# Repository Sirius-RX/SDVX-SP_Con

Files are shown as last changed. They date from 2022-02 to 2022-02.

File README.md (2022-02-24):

# SDVX-SP_Con
An Arcade PC Controller for SDVX. At the same time, the scheme is compatible with O.N.G.E.K.I Controller and IIDX Controller.

一个SDVX手台 同时方案兼容音击和IIDX。

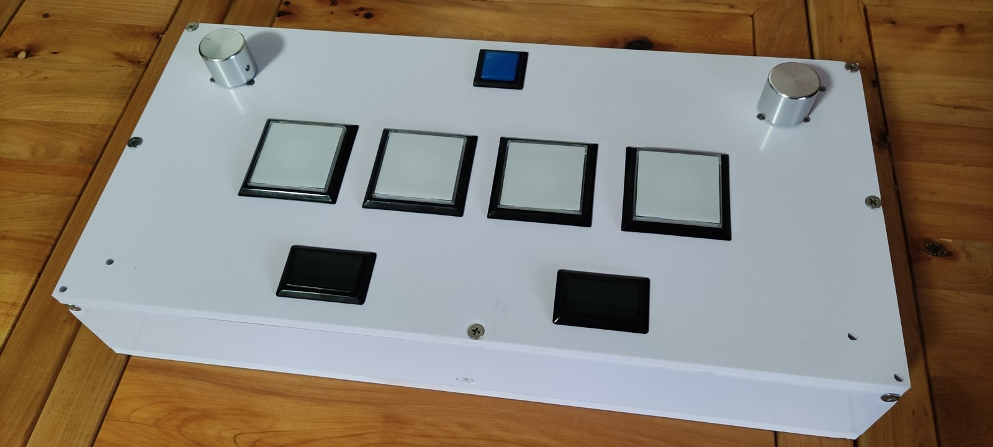
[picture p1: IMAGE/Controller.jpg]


# 特性(Features)

- 较低的成本（我大概全加起来花了680，包括压线钳）
- 近乎最好的游戏体验（除了换三合按键，没有升级空间了）
- 较轻的重量（没有称量设备，但是比源台那个铁疙瘩是轻了特别多）
- 理论最快响应速度的按键（详情请见代码）
- 在自制手台中杰出的体积控制（46X22X8.5cm；对比源台是49X22X6cm）

# 需要的准备

### 手台核心部件

- SDVX按键一套，包括：
  - 4x  BT（大-白色正方形按钮）
  
  - 2x  FX（黑色长方形按钮）
  
  - 1x  START键
    注：购买按键的时候需要**保证按键加上微动的长度不超过60mm**，因为外壳内部空间的高度就是65mm，星韵按键正好可以塞进去
  
    链接：[【星韵】音律炫动 Sound Voltex SDVX 音击 维修 按钮 按键 DIY-淘宝网 (taobao.com)](https://item.taobao.com/item.htm?spm=a1z09.2.0.0.7a892e8d3jQ369&id=611586858628&_u=n207q98786659d)
  
- 7x  按键对应微动  链接：[原装进口欧姆龙微动开关D2MV-01-1C1正品1C3小型限位行程开关超轻-淘宝网 (taobao.com)](https://item.taobao.com/item.htm?spm=a1z09.2.0.0.7a892e8d3jQ369&id=575465816885&_u=n207q987866546)

- 5x(最少，越多越好)  5V蓝色按键配件LED  链接：[24V大中小圆按键配件LED迷你灯-5V带灯按钮游戏机普通款12V灯泡-淘宝网 (taobao.com)](https://item.taobao.com/item.htm?spm=a1z09.2.0.0.7a892e8d3jQ369&id=25422216606&_u=n207q98786c70a)

- 2x(最少，越多越好)  5V红色按键配件LED  链接：[24V大中小圆按键配件LED迷你灯-5V带灯按钮游戏机普通款12V灯泡-淘宝网 (taobao.com)](https://item.taobao.com/item.htm?spm=a1z09.2.0.0.7a892e8d3jQ369&id=25422216606&_u=n207q98786c70a)

- 2x  编码器（单片机5V专用，正交型，即AB相输出）链接：[全新编码器脉冲型号齐ABABZ差分编码器旋转编码器直销定制编码器-淘宝网 (taobao.com)](https://item.taobao.com/item.htm?spm=a1z09.2.0.0.7a892e8d3jQ369&id=640404233664&_u=n207q987860373)

- 2x  编码器旋钮（30*25mm）  链接：[全铝旋钮 实心铝合金旋钮 胆机功放音量电位器旋钮齿帽 25mm 30mm-淘宝网 (taobao.com)](https://item.taobao.com/item.htm?spm=a1z09.2.0.0.7a892e8d3jQ369&id=537307977071&_u=n207q987860a54)

### 外壳&安装

- 1x  PVC 外壳（由6块面板构成，使用CADFiles文件夹下的CAD文件制作，推荐一家叫“多美歌广告的淘宝店”）  链接：[pvc雪弗板立体广告字uv定制做亚克力水晶字招牌门头户外装饰创意-淘宝网 (taobao.com)](https://item.taobao.com/item.htm?spm=a1z09.2.0.0.7a892e8d3jQ369&id=658262089977&_u=n207q98786d1a2)
- 20x(最少，越多越好)  25mm M5沉头自攻螺丝（用来安装外壳）  链接：[促316不锈钢十字平头自攻螺丝钉沉头自攻丝木螺丝M2M2.6M3M4M5M6-tmall.com天猫](https://detail.tmall.com/item.htm?id=17087667260&spm=a1z09.2.0.0.7a892e8d3jQ369&_u=n207q9878652ab)
- 6x(最少，越多越好)  16mm M5沉头螺丝（普通螺纹，用来安装编码器）  链接：[促平头螺丝304不锈钢沉头螺丝钉螺母配件大全螺栓M1M3M4M5M6M8M10-tmall.com天猫](https://detail.tmall.com/item.htm?id=15817242523&spm=a1z09.2.0.0.7a892e8d3jQ369&_u=n207q98786515a)
- 4x(最少，越多越好)  3（螺纹直径mm）*7（六角长度 mm）+3（螺纹长度 mm）的铜柱（用来固定PCB）  链接：[促单头六角铜柱M3M4电脑主板六角隔离柱机箱螺柱螺丝M2M2.5+3+4+6-tmall.com天猫](https://detail.tmall.com/item.htm?id=17318980620&spm=a1z09.2.0.0.7a892e8d3jQ369&_u=n207q98786f661)
- 4x(最少，越多越好)  5mm M3螺丝（普通螺纹，用来固定PCB）
- 1x  502粘合剂（用来固定铜柱）
- 1x  M3钻头（用来给铜柱固定位钻孔）

##### 		可选

  - 4x(最少，越多越好)  25mm M5螺丝（普通螺纹，如果想安装UV面板需要）
  - 8x(最少，越多越好)  M5垫片（诺干，同上用来安装UV面板）
  - 4x(最少，越多越好)  M5自锁螺母
  - 4x  脚垫（类似机箱的那种，预留了4个M5的安装孔位）

### Hardware 

- 1x  PCB（能用**Hardware**中的gerber文件制作[gerber_SPCon.zip]，制作方式参考下文**Hardware部分**）

- PCB需要的器件，详情参考表**Hardware/SPCon.pdf**第三页

  	这里特别给一下轻触开关和CH557商品链接，这两个不太好找：

  	开关：[GT-TC018A-H0375-L1_（G-Switch(品赞)）GT-TC018A-H0375-L1中文资料_价格_PDF手册-立创电子商城 (szlcsc.com)](https://item.szlcsc.com/1046870.html)

  	CH557Q：[8位增强型单片机: CH557-淘宝网 (taobao.com)](https://item.taobao.com/item.htm?spm=a1z10.3-c.w4002-2002130774.9.36ad267auUZI8O&id=534290249622)

- 1x  电烙铁

- 7x(最少，越多越好)  4P XH2.54转插簧6.3转接线：

  淘宝上没有卖现成的，有两种准备方法

  1. 可以买压线钳自己压线[笔者做法，耗时费力]，但是编码器那边直接用压线钳压XH2.54头子就很方便；
  
     	半成品线链接（6.3插簧 20cm 0.5平方 单头）：[现货2.8 4.8 6.3mm插簧端子带线加护套 插片公母线束加工冷压接线-淘宝网 (taobao.com)](https://item.taobao.com/item.htm?id=529701497995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)
  
     	压线钳链接（SN-01BM）：[线割SN-2549/01BM杜邦1.25/PH2.0/XH2.54/5557汽车端子插簧压线钳-淘宝网 (taobao.com)](https://item.taobao.com/item.htm?spm=a1z09.2.0.0.7a892e8d3jQ369&id=538370306938&_u=n207q98786dee1)
  
  2. 找淘宝店定制，只需将4P XH2.54转插簧6.3转接线描述文字发给淘宝电商即可，但是编码器接线需要做其它处理，详见**组装部分/9.**，实物如下图
  
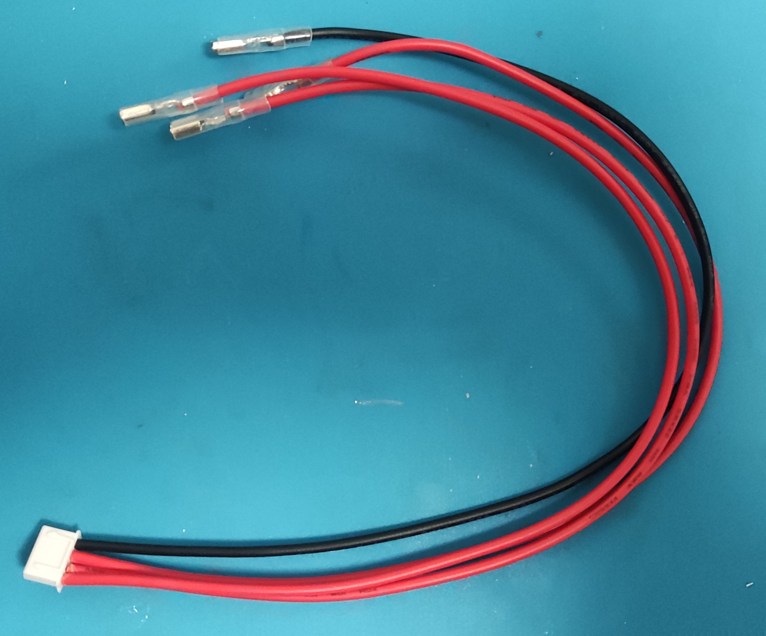
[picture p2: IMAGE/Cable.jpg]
Cable
  

  注：PCB上的元器件在Hardware中的SPCon.pdf文件第三章中有详细信息

### Software

- WCHISPTool(用来给MCU下载程序)

# Hardware部分

1. 下载嘉立创PCB下单助手（下载地址https://download.jlc.com/jlchelper/release/3.4.5/JLCPcAssit_setup_3.4.5.zip?pname=quote_order）

2. 将**Hardware**中的gerber_SPCon.zip投至立创PCB下单助手中下单

3. 在立创商城或者淘宝购买焊接需要的相应的物品，MCU使用的是WCH的CH557，其它杂项可以根据**Hardware/SPCon.pdf**的第三页参考购买，串口功能区如果不需要的话可以不用购买响应的物品（CH340，USB_DG等）

4. PCB板焊接，串口功能区如果不需要的话可以不用焊接（CH340，USB_DG等）

   注意：PCB上每一个按键接口旁边都有一个电容的焊盘，在清单中是100nF的电容，这些电容本来一开始是想用来做按键的硬件滤波，后来经过示波器测试之后发现**加上滤波电容后按键响应时间从原来的80ns变为了2us，建议和我一样不用焊接。**

   成品如下图
   
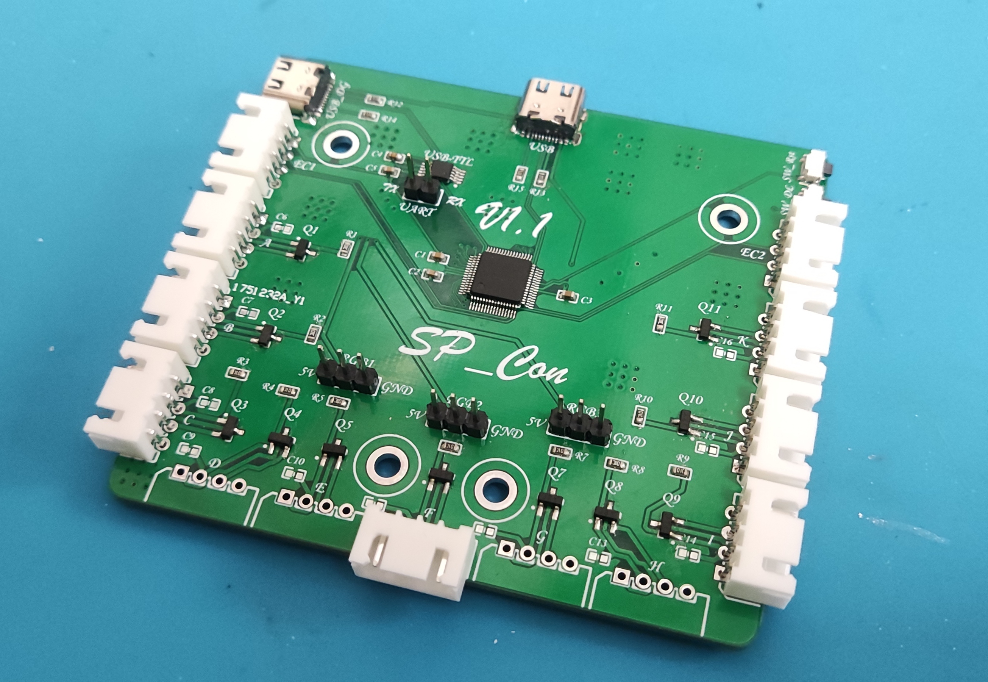
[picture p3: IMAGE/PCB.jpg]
   

# Software部分

1. 下载WCHISPTool（下载链接 http://www.wch.cn/downloads/file/196.html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 ）

2. **按住PCB板上的按键SW_DL后**，插上USB线，如下图

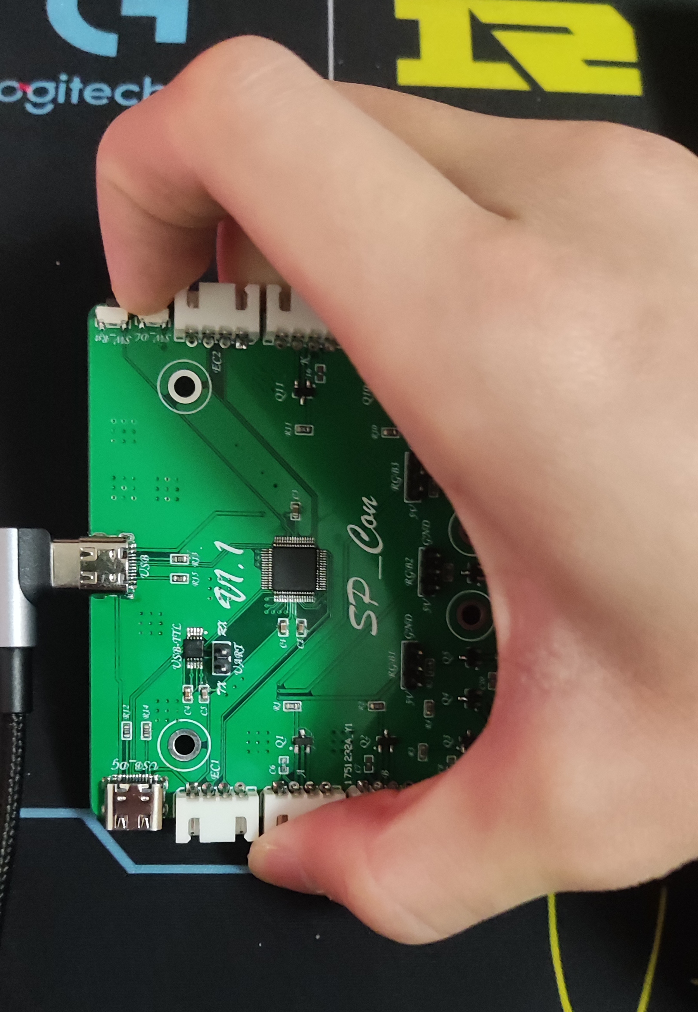
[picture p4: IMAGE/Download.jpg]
Download
   

3. 此时WCHISPTool应当会自动检测到芯片CH557（如果没有请检查CH557是否虚焊），程序选择**Software/Objects**下的CH557.hex，如下图

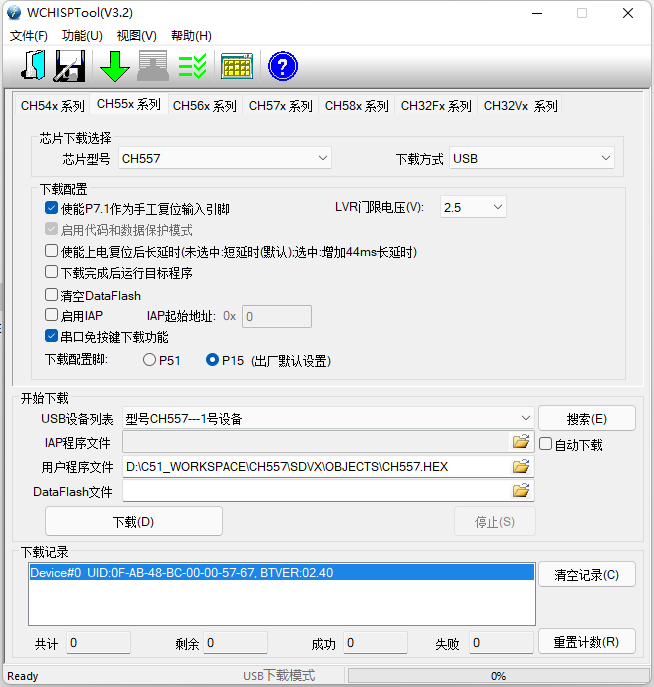
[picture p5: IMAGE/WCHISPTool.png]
WCHISPTool
   

4. 点击下载

4. 重新插拔供电线，或者按下SW_Rst后，打开系统设备管理器，观察设备中是否多出来了一个鼠标和键盘

# 组装部分

- 面板的主要固定方式是螺丝固定

- 面板的摆放类似于夹汉堡——顶面板和底面板夹住前后面板和侧面板

  安装孔位示意如下

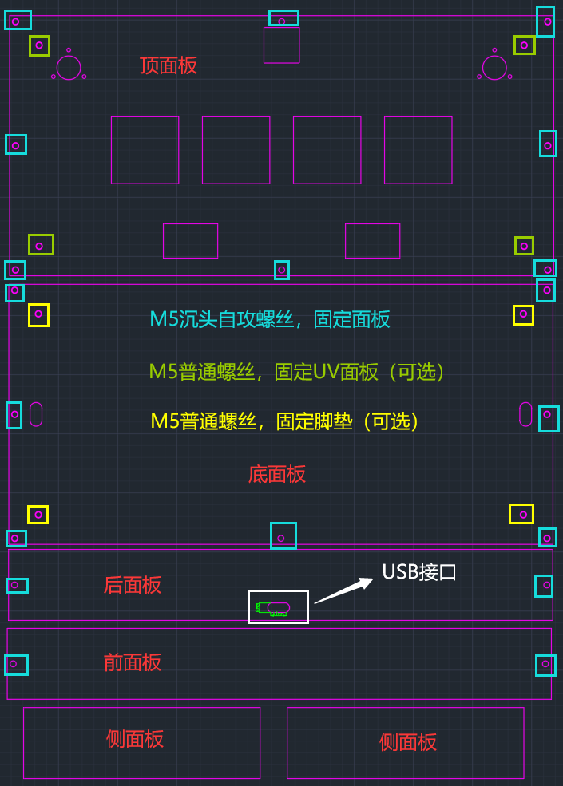
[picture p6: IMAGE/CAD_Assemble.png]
CAD_Assemble
  

  ### **安装过程**

  1. 首先通过螺丝将底面板和后面板固定在一起，注意用底面板2个螺丝孔的一侧固定后面板，不要使用3个螺丝孔的一侧

  2. 将PCB的USB口对准后面板的USB接口开槽，找到PCB上4个螺丝安装位在底面板上的对应的点

  3. 使用M3钻头进行钻孔，注意孔位一定要对准，而且千万不要将PVC板打穿了（如果不小心打穿了，可以使用25mm M3螺丝 + 3*7双通六角铜柱 + M3螺母 + 脚垫的方式固定）

  4. 将502粘合剂倒入刚刚钻好的孔洞之后，并将四个铜柱按入其中

  5. 等待502固化后，安装PCB板

  6. 在顶面板上安装按键，微动

  6. 在顶板面上通过6个16mm M5沉头螺丝安装编码器
  
  6. 将4P XH2.54转插簧6.3转接线插入PCB的A~K的任意槽中，如下图（图中的EC1与EC2口接上了，那两个接口是用来接编码器的，先无视它们）
  
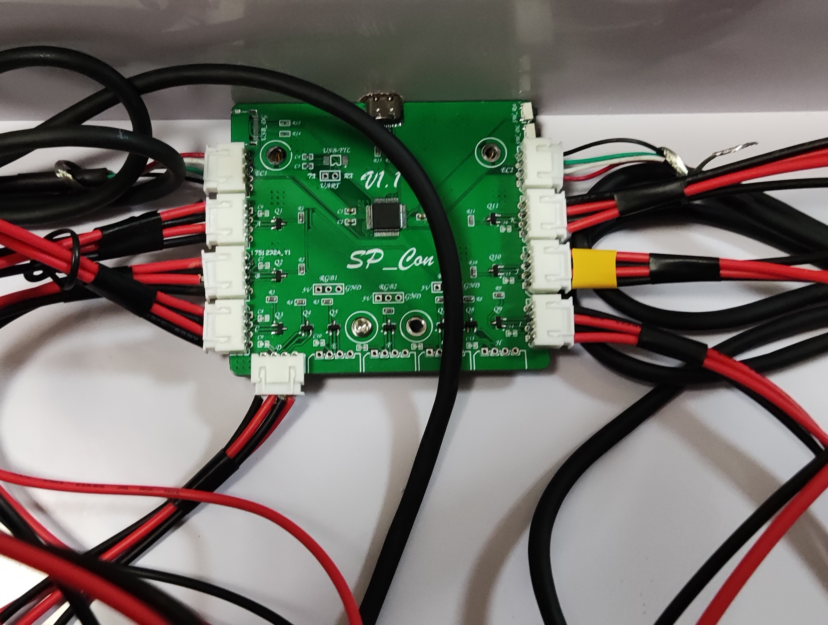
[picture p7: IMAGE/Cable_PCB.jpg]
Cable_PCB
     
     
  7. 将4P XH2.54转插簧6.3转接线插入微动和LED接口上，线序如下图，注意不要接错
  
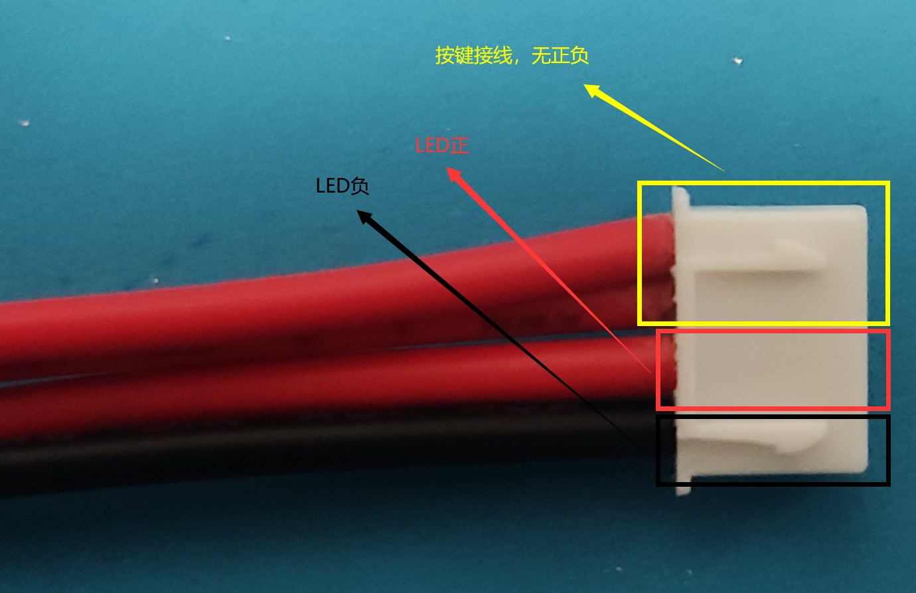
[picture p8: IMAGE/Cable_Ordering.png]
Cable_Ordering
     
     
     接好后如下图
     
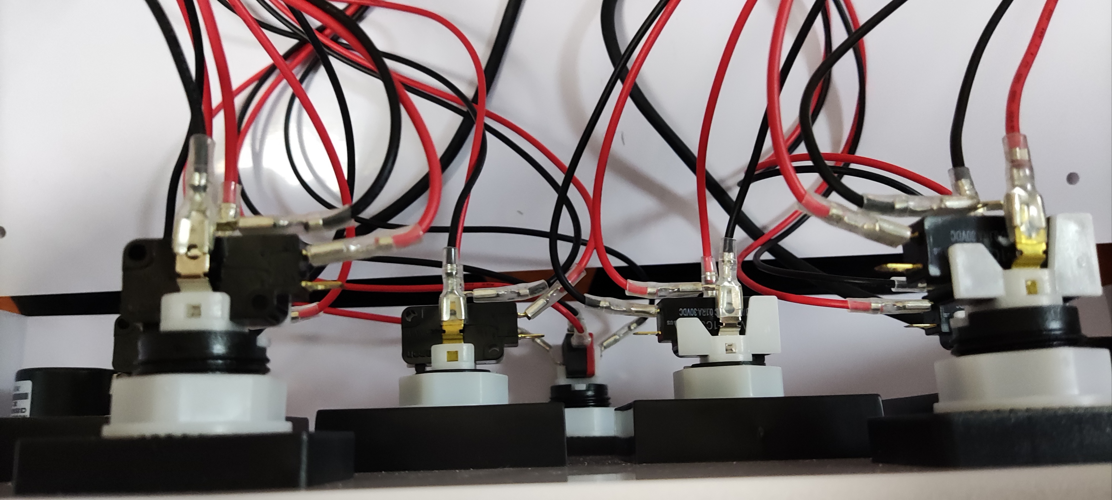
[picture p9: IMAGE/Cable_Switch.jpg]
Cable_Switch
     
  
  9. 编码器接线处理
  
     - 如果是购买压线钳自己压线的话，直接压XH2.54头子插上去就完了
  
     - 如果是定制的线的话，可以使用烙铁头在编码器的线头上焊接一根公母杜邦线，通过杜邦线的母口插在PCB的XH2.54接口上
  
     编码器线序如下
     
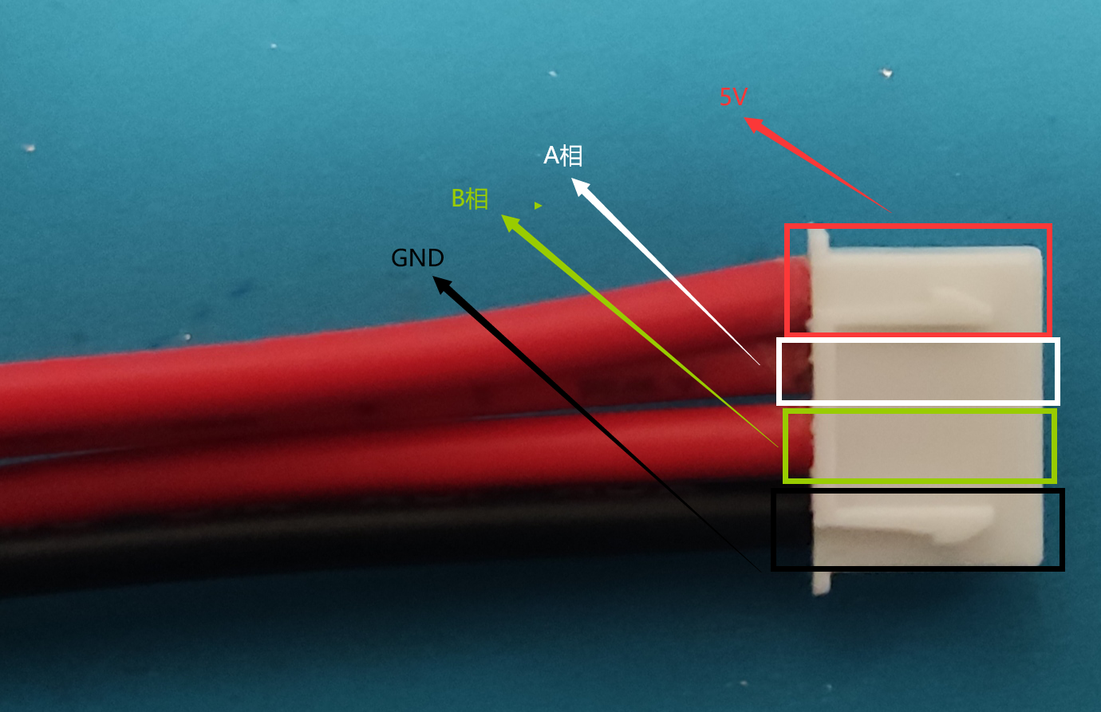
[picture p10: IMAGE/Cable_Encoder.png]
Cable_Encoder
     
     
  11. 将两个编码器对应的线插入到PCB中EC1，EC2接口，注意不要接错线
  
  12. 将外壳安装完毕
  
      **注意：**安装外壳前，一定要保证所有需要的线都接上了，并且接的比较紧，一旦安装好外壳后，由于是自攻螺丝固定的外壳，拆下后重新安装将不能保证连接的稳定性！

  ### 恭喜您，至此您已经获得了一个成本较低，并且体验较佳的SDVX手台！

## 如果您需要一个音击或者IIDX手台的话，可以直接使用该方案中的代码和PCB板，只需要按自己所需要的数量进行接线和设计外壳即可！

## 另外PCB板上预留了3个RGB接针（PWM0，PWM1，PWM2），有需要的可以自己根据源代码框架进行RGB灯效的制作！（做好了戳我，我也想白嫖）

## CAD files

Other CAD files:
Software/Objects/HID_Main.obj
CADFiles/FramWork(CAD2022).dwg
Software/Objects/MouseKey.obj
CADFiles/FramWork(CAD2013).dwg
Software/Objects/Debug.obj
Software/Objects/CompositeKM.obj
Software/Objects/HID.obj
Software/Objects/Mouse_Key.obj

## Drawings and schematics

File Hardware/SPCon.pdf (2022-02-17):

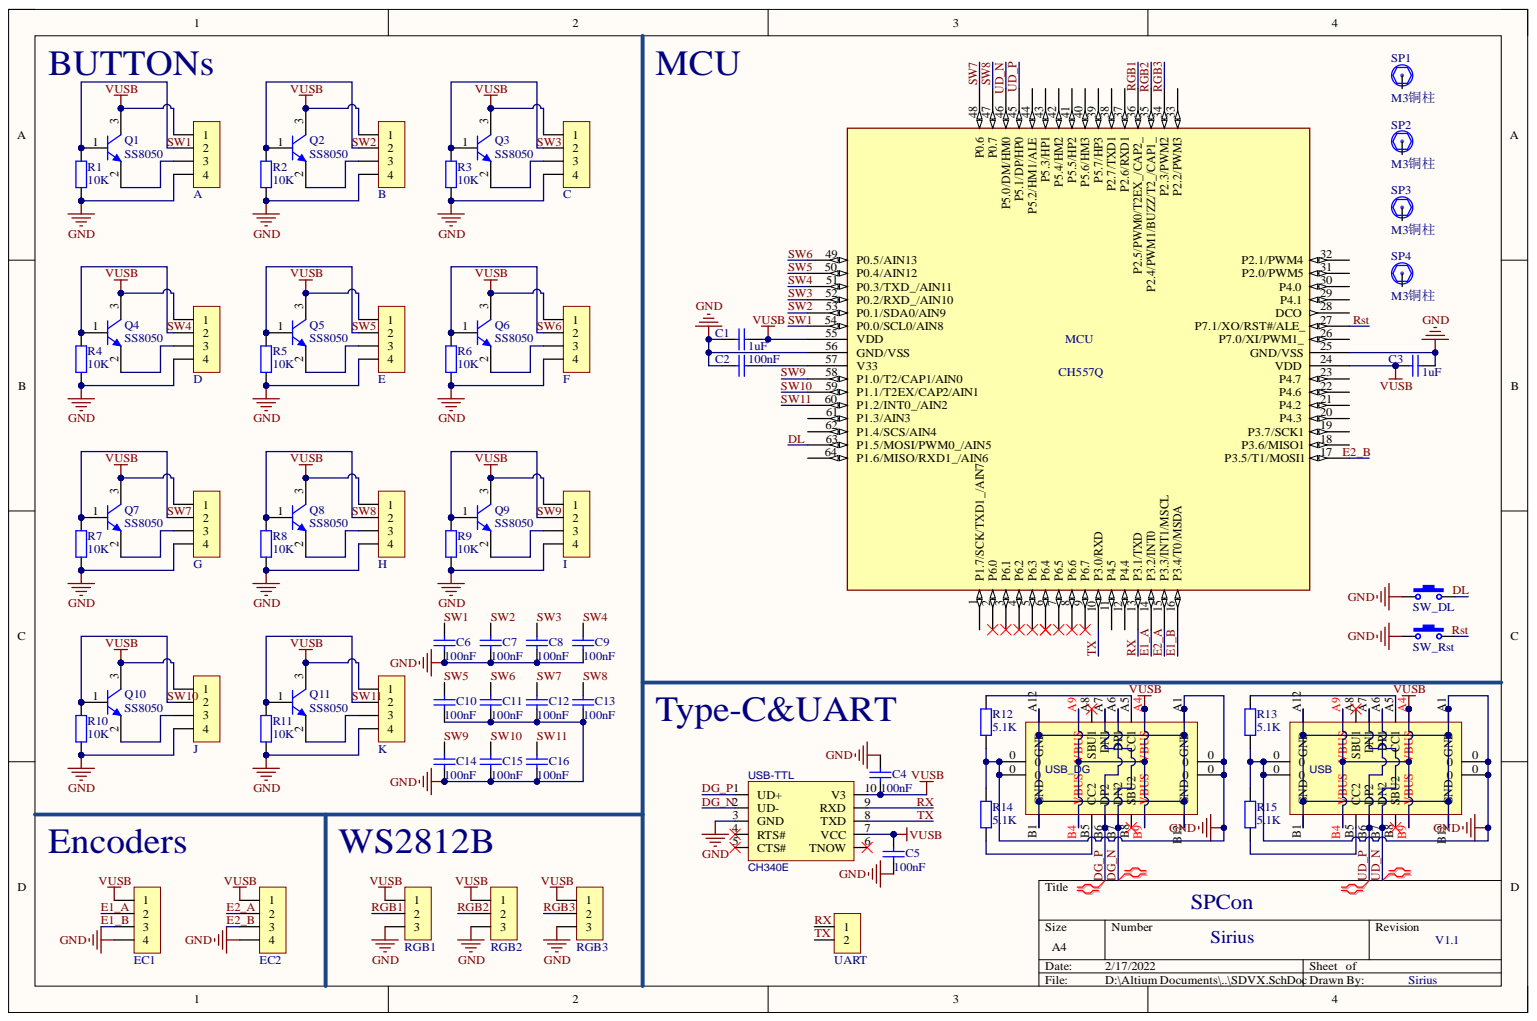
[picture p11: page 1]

1 u | 5 6 | 2 5
C2 | | 1 0 0 n F 5 7 | 2 4 | C3

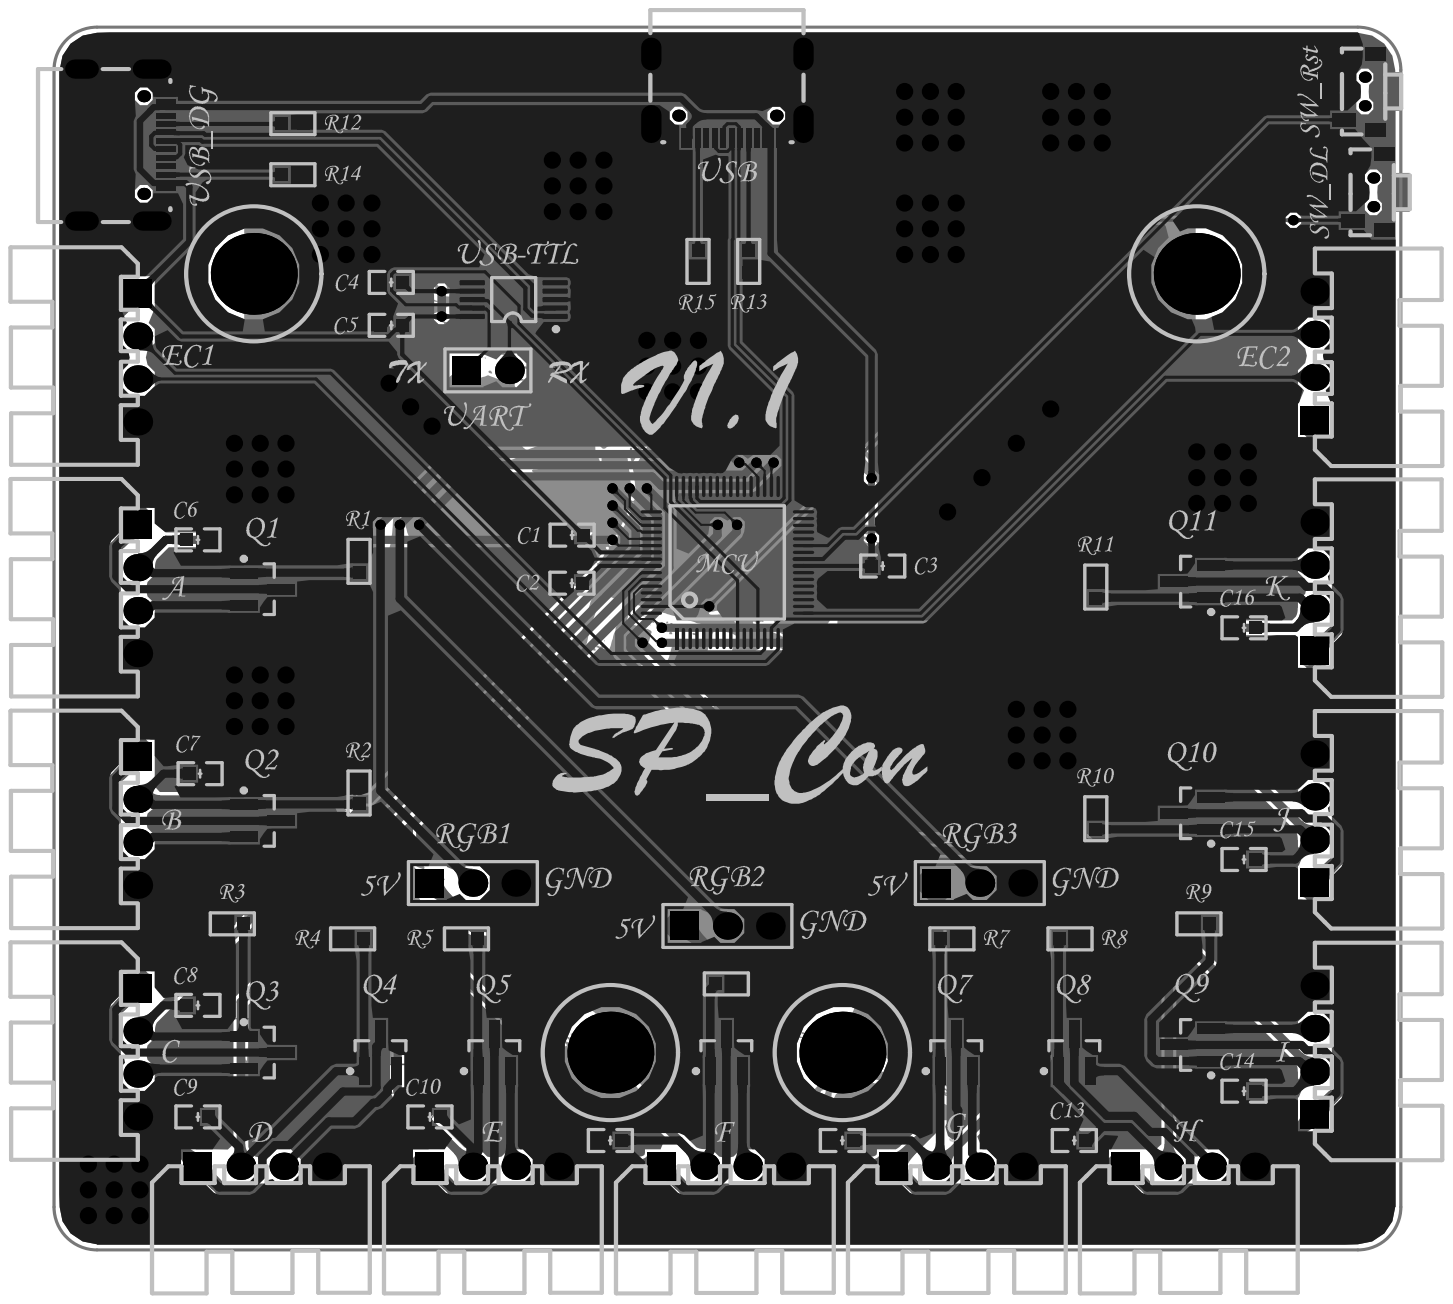
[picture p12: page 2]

Comment | Description | Designator | Footprint | LibRef | Quantity
HDR-1X4 | 4P接插件 | A, B, C, D, E, EC1, EC2, F, G, H, I, J, K | XH2.54-WI-4P | Header 4 | 13
1uF | 贴片电容 | C1, C3 | C0603_L | C | 2
100nF | 贴片电容 | C2, C4, C5, C6, C7, C8, C9, C10, C11, C12, C13, C14, C15, C16 | C0603_L | C | 14
CH557Q | 8bit MCS51 MCU with ADC & USB host 4 ports & USB device & RGB PWM & dual UART & SPI & I2C | MCU | LQFP64 | CH557Q | 1
SS8050 | NPN三极管 | Q1, Q2, Q3, Q4, Q5, Q6, Q7, Q8, Q9, Q10, Q11 | SOT23-3M | BCP68 | 11
10K | 贴片电阻 | R1, R2, R3, R4, R5, R6, R7, R8, R9, R10, R11 | R0603_L | R | 11
5.1K | 贴片电阻 | R12, R13, R14, R15 | R0603_L | R | 4
HDR-1X3 | 3P接插件 | RGB1, RGB2, RGB3 | HDR2.54-LI-3P | Header 3 | 3
M3铜柱 | 铜柱 | SP1, SP2, SP3, SP4 | M3x4_L | 铜柱小焊盘 | 4
3x6x5 | 轻触开关 | SW_DL, SW_Rst | SW-SMD_L4.7-W3.5-P3.35-EH | SW | 2
HDR-1X2 | 2P接插件 | UART | HDR2.54-LI-2P | Header 2 | 1
TYPE-C 2.0 -16P | USB2.0 Type-C 16Pin 母座 | USB, USB_DG | USB-C-SMD_16P | USB2.0_Type-C_16Pin | 2
CH340E | USB转串口芯片，内 置时钟 | USB-TTL | MSOP-10 | CH340E | 1

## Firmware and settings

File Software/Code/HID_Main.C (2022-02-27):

/********************************** (C) COPYRIGHT *******************************
* File Name          : CompositeKM.C
* Author             : Sirius_P
* Version            : V1.1
* Date               : 2022/02/05
* Description        : CH557模拟USB键鼠复合设备,支持类命令,支持唤醒
                       演示键盘鼠标简单操作。其他键值，参考 HID USAGE TABLE协议文档
							  任意字符：主机睡眠状态下,设备远程唤醒主机（注意设备一般需自供电,因为主机休眠可能USB口也会掉电）
*******************************************************************************/
#include "DEBUG.H"
#include "MouseKey.H"

#define Fullspeed//全速USB模式选择，如使用半速则注释

#ifdef  Fullspeed
#define THIS_ENDP0_SIZE         64
#else
#define THIS_ENDP0_SIZE         8          //低速USB，中断传输、控制传输最大包长度为8
#endif

#define ENDP1_IN_SIZE           2          //键盘端点数据包大小
#define ENDP2_IN_SIZE           2          //鼠标端点数据包大小
#define Sense                   1          //旋钮灵敏度

UINT8X  Ep0Buffer[MIN(64, THIS_ENDP0_SIZE + 2)] _at_ 0x0000;                  //端点0 OUT&IN缓冲区，必须是偶地址
UINT8X  Ep1Buffer[MIN(64, ENDP1_IN_SIZE)]     _at_ MIN(64, THIS_ENDP0_SIZE + 2); //端点1 IN缓冲区,必须是偶地址
UINT8X  Ep2Buffer[MIN(64, ENDP2_IN_SIZE)]     _at_ (MIN(64, THIS_ENDP0_SIZE + 2) + MIN(64, ENDP1_IN_SIZE + 2)); //端点2 IN缓冲区,必须是偶地址

UINT8   SetupReq, Ready, UsbConfig;

#define UsbSetupBuf     ((PUSB_SETUP_REQ)Ep0Buffer)

#pragma NOAREGS

/*设备描述符*/
UINT8C DevDesc[] =
{
    0x12,                                  //bLength
    0x01,                                  //bDescriptorType
    0x10, 0x01,                            //bcdUSB
    0x00,                                  //bDeviceClass
    0x00,                                  //bDeviceSubClass
    0x00,                                  //bDeviceProtocol
    THIS_ENDP0_SIZE,                       //bMAXPacketSize0
    0x86, 0x1a,                            //idVendor
    0xe1, 0xe6,                            //idProduct
    0x00, 0x01,                            //bcdDevice
    0x01,                                  //iManufacturer
    0x02,                                  //iProduct
    0x00,                                  //iSerialNumber
    0x01                                   //bNumConfigurations
};
/*字符串描述符*/
UINT8C  MyLangDescr[] = { 0x04, 0x03, 0x09, 0x04 };                                     // 语言描述符
UINT8C  MyManuInfo[] = { 0x0E, 0x03, 'S', 0, 'i', 0, 'r', 0, 'i', 0, 'u', 0, 's', 0 };  // 厂家信息
UINT8C  MyProdInfo[] = { 0x0C, 0x03, 'S', 0, 'P', 0, 'C', 0, 'o', 0, 'n', 0 };          // 产品信息
/*HID类报表描述符*/
UINT8C KeyRepDesc[] =
{
    0x05, 0x01,                                        //Usage Page (Generic Desktop)
    0x09, 0x06,                                        //Usage (Keyboard)
    0xA1, 0x01,                                        //Collection (Application)
    /*上传数据*/
    //第1-2字节前3比特
    0x05, 0x07,                                        //Usage Page (Keyboard/Keypad)
    0x19, 0x04,                                        //Usage Minimum
    0x29, 0x0E,                                        //Usage Maximum
    0x15, 0x00,                                        //Logical Minimum
    0x25, 0x01,                                        //Logical Maximum
    0x95, 0x0B,                                        //Report Count
    0x75, 0x01,                                        //Report Size
    0x81, 0x02,                                        //Input (Data,Variable,Absolute)
    //第2字节后5比特
    0x95, 0x05,                                        //Report Count
    0x75, 0x01,                                        //Report Size
    0x81, 0x01,                                        //Input (Constant)
    0xC0                                               //End Collection
};
UINT8C MouseRepDesc[] =
{
    0x05, 0x01,                                        //Usage Page (Generic Desktop)
    0x09, 0x02,                                        //Usage (Mouse)
    0xA1, 0x01,                                        //Collection (Application)
    /*上传数据*/
    //第1-2字节
    0x05, 0x01,                                      	 //Usage Page (Generic Desktop)
    0x09, 0x30,                                        //Local X
    0x09, 0x31,                                        //Local Y
    0x15, 0x81,                                        //Logical Minimum
    0x25, 0x7f,                                        //Logical Maximum
    0x95, 0x02,                                        //Report Count
    0x75, 0x08,                                        //Report Size
    0x81, 0x06,                                        //Input (Data,Variable,Relative)
    0xC0                                               //End Collection
};
/*配置描述符*/
UINT8C CfgDesc[] =
{
    /*配置描述符*/
    0x09,                                              //bLength
    0x02,                                              //bDescroptorType
    0x3b, 0x00,                                        //wTotalLength
    0x02,                                              //bNumInterfaces
    0x01,                                              //bConfigurationValue
    0x00,                                              //iConfiguration
    0xA0,                                              //bmAttributes
    0x96,                                              //MaxPower

    /*接口描述符，键盘功能*/
    0x09,                                              //bLength
    0x04,                                              //bDescriptorType
    0x00,                                              //bInterfaceNumber
    0x00,                                              //bAlternateSetting
    0x01,                                              //bNumEndpoints
    0x03,                                              //bInterfaceClass
    0x01,                                              //bInterfaceSubClass
    0x01,                                              //bInterfaceProtocol
    0x00,                                              //iInterface
    /*HID类描述符*/
    0x09,                                              //bLength
    0x21,                                              //bDescriptorType
    0x11, 0x01,                                        //bcdHID
    0x00,                                              //bCountryCode
    0x01,                                              //bNumDescriptors
    0x22,                                              //DescriptorType
    sizeof(KeyRepDesc) & 0xFF, sizeof(KeyRepDesc) >> 8, //wDescriptorLength
    /*端点描述符*/
    0x07,                                              //bLength
    0x05,                                              //bDescriptorType
    0x81,                                              //bEndpointAddress
    0x03,                                              //bmAttributes
    ENDP1_IN_SIZE, 0x00,                               //wMaxPacketSize
    0x0a,                                              //bInterval,ms
	 
    /*接口描述符，鼠标功能*/
    0x09,                                              //bLength
    0x04,                                              //bDescriptorType
    0x01,                                              //bInterfaceNumber
    0x00,                                              //bAlternateSetting
    0x01,                                              //bNumEndpoints
    0x03,                                              //bInterfaceClass
    0x01,                                              //bInterfaceSubClass
    0x02,                                              //bInterfaceProtocol
    0x00,                                              //iInterface
    /*HID类描述符*/
    0x09,                                              //bLength
    0x21,                                              //bDescriptorType
    0x10, 0x01,                                        //bcdHID
    0x00,                                              //bCountryCode
    0x01,                                              //bNumDescriptors
    0x22,                                              //DescriptorType
    sizeof(MouseRepDesc) & 0xFF, sizeof(MouseRepDesc) >> 8, //wDescriptorLength
    /*端点描述符*/
    0x07,                                              //bLength
    0x05,                                              //bDescriptorType
    0x82,                                              //bEndpointAddress
    0x03,                                              //bmAttributes
    ENDP2_IN_SIZE, 0x00,                               //wMaxPacketSize
    0x0a                                               //bInterval,ms
};
/*键盘数据*/
UINT8 HIDKey[ENDP1_IN_SIZE];
/*鼠标数据*/
UINT8 HIDMouse[2] = { 0x0, 0x0 };
UINT8 Endp1Busy = 0;                                  //传输完成控制标志位
UINT8 Endp2Busy = 0;
UINT8 WakeUpEnFlag = 0;                               //远程唤醒使能标志

/*******************************************************************************
* Function Name  : Enp1IntIn
* Description    : USB设备模式端点1的中断上传
* Input          : *buf: 上传数据
*                  len:上传数据长度
* Return         : None
*******************************************************************************/
void Enp1IntIn( UINT8 *buf, UINT8 len )
{
    memcpy( Ep1Buffer, buf, len );                                            //加载上传数据
    UEP1_T_LEN = len;                                                         //上传数据长度
    UEP1_CTRL = UEP1_CTRL & ~ MASK_UEP_T_RES | UEP_T_RES_ACK;                 //有数据时上传数据并应答ACK
}

/*******************************************************************************
* Function Name  : Enp2IntIn1
* Description    : USB设备模式端点2的中断上传函数
* Input          : *buf: 上传数据
*                  len:上传数据长度
* Return         : None
*******************************************************************************/
void Enp2IntIn( UINT8 *buf, UINT8 len )
{
    memcpy( Ep2Buffer, buf, len);                                             //加载上传数据
    UEP2_T_LEN = len;                                                         //上传数据长度
    UEP2_CTRL = UEP2_CTRL & ~ MASK_UEP_T_RES | UEP_T_RES_ACK;                 //有数据时上传数据并应答ACK
}

/*******************************************************************************
* Function Name  : USB_DeviceInterrupt
* Description    : USB中断服务程序
* Input          : None
* Return         : None
*******************************************************************************/
void	USB_DeviceInterrupt(void) interrupt INT_NO_USB using 1
{
    UINT8	len;
    static	UINT8	SetupReqCode;
    static  UINT16 SetupLen;
    static	PUINT8	pDescr;
    if(UIF_TRANSFER)  // USB传输完成
    {
USB_DevIntNext:
        switch(USB_INT_ST & ( bUIS_SETUP_ACT | MASK_UIS_TOKEN | MASK_UIS_ENDP ))  //分析操作令牌和端点号
        {
        case UIS_TOKEN_IN | 2:  // endpoint 2# 批量端点上传
        case bUIS_SETUP_ACT | UIS_TOKEN_IN | 2:
            UEP2_T_LEN = 0;                                                       //预使用发送长度一定要清空
            UEP2_CTRL ^= bUEP_T_TOG;                                              //手动翻转
            Endp2Busy = 0;                                                        
            UEP2_CTRL = UEP2_CTRL & ~ MASK_UEP_T_RES | UEP_T_RES_NAK;             //默认应答NAK
            break;                                                                
        case UIS_TOKEN_IN | 1:  // endpoint 1# 中断端点上传                       
        case bUIS_SETUP_ACT | UIS_TOKEN_IN | 1:                                   
            UEP1_T_LEN = 0;                                                       //预使用发送长度一定要清空
            UEP1_CTRL ^= bUEP_T_TOG;                                              //手动翻转
            Endp1Busy = 0;                                                        
            UEP1_CTRL = UEP1_CTRL & ~ MASK_UEP_T_RES | UEP_T_RES_NAK;             //默认应答NAK
            break;                                                                
        case UIS_TOKEN_IN | 0:  // endpoint 0# IN
        case bUIS_SETUP_ACT | UIS_TOKEN_IN | 0:
            switch(SetupReqCode)
            {
            case USB_GET_DESCRIPTOR:
                len = SetupLen >= THIS_ENDP0_SIZE ? THIS_ENDP0_SIZE : SetupLen;   //本次传输长度
                memcpy( Ep0Buffer, pDescr, len );  /* 加载上传数据 */
                SetupLen -= len;
                pDescr += len;
                UEP0_T_LEN = len;
                UEP0_CTRL ^= bUEP_T_TOG;  // 翻转
                break;
            case USB_SET_ADDRESS:
                USB_DEV_AD = USB_DEV_AD & bUDA_GP_BIT | SetupLen;
                UEP0_CTRL = UEP_R_RES_ACK | UEP_T_RES_NAK;
                break;
            default:
                UEP0_T_LEN = 0;  // 状态阶段完成中断或者是强制上传0长度数据包结束控制传输
                UEP0_CTRL = UEP_R_RES_ACK | UEP_T_RES_NAK;
                break;
            }
            break;
        case UIS_TOKEN_OUT | 0:  // endpoint 0# OUT
        case bUIS_SETUP_ACT | UIS_TOKEN_OUT | 0:
            UEP0_CTRL ^= bUEP_R_TOG;                                      //同步标志位翻转
            break;
        default:
            if ((USB_INT_ST & (bUIS_SETUP_ACT | MASK_UIS_TOKEN)) == (bUIS_SETUP_ACT | UIS_TOKEN_FREE))  // endpoint 0# SETUP
            {
                UEP0_CTRL = bUEP_R_TOG | bUEP_T_TOG | UEP_R_RES_ACK | UEP_T_RES_ACK;
                SetupLen = ((UINT16)UsbSetupBuf->wLengthH << 8) + UsbSetupBuf->wLengthL;
                len = 0;
                SetupReqCode = UsbSetupBuf->bRequest;
                if( UsbSetupBuf->wLengthH || SetupLen > 0x7F) SetupLen = 0x7F;  // 限制总长度
                len = 0;  // 默认为成功并且上传0长度
                if ((UsbSetupBuf->bRequestType & USB_REQ_TYP_MASK) != USB_REQ_TYP_STANDARD)
                {
                    switch(SetupReqCode)
                    {
                    case 0x01://GetReport
                        break;
                    case 0x02://GetIdle
                        break;
                    case 0x03://GetProtocol
                        break;
                    case 0x09://SetReport
                        break;
                    case 0x0A://SetIdle
                        break;
                    case 0x0B://SetProtocol
                        break;
                    default:
                        len = 0xFFFF;                                  /*命令不支持*/
                        break;
                    }
                }
                else  // 标准请求
                {
                    switch(SetupReqCode)  // 请求码
                    {
                    case USB_GET_DESCRIPTOR:
                        switch(UsbSetupBuf->wValueH )
                        {
                        case 1:  // 设备描述符
                            pDescr = (PUINT8)( &DevDesc[0] );
                            len = sizeof( DevDesc );
                            break;
                        case 2:  // 配置描述符
                            pDescr = (PUINT8)( &CfgDesc[0] );
                            len = sizeof( CfgDesc );
                            break;
                        case 3:  // 字符串描述符
                            switch(UsbSetupBuf->wValueL)
                            {
                            case 1:
                                pDescr = (PUINT8)( &MyManuInfo[0] );
                                len = sizeof( MyManuInfo );
                                break;
                            case 2:
                                pDescr = (PUINT8)( &MyProdInfo[0] );
                                len = sizeof( MyProdInfo );
                                break;
                            case 0:
                                pDescr = (PUINT8)( &MyLangDescr[0] );
                                len = sizeof( MyLangDescr );
                                break;
                            default:
                                len = 0xFF;  // 不支持的字符串描述符
                                break;
                            }
                            break;
                        case USB_DESCR_TYP_REPORT:
                            if(UsbSetupBuf->wIndexL == 0)                   //接口0报表描述符
                            {
                                pDescr = KeyRepDesc;                        //数据准备上传
                                len = sizeof(KeyRepDesc);
                            }
                            else if(UsbSetupBuf->wIndexL == 1)              //接口1报表描述符
                            {
                                pDescr = MouseRepDesc;                      //数据准备上传
                                len = sizeof(MouseRepDesc);
                            }
                            else
                            {
                                len = 0xFFFF;                                 //本程序只有2个接口，这句话正常不可能执行
                            }
                            break;
                        default:
                            len = 0xFF;  // 不支持的描述符类型
                            break;
                        }
                        if(SetupLen > len) SetupLen = len;  // 限制总长度
                        len = SetupLen >= THIS_ENDP0_SIZE ? THIS_ENDP0_SIZE : SetupLen;  // 本次传输长度
                        memcpy(Ep0Buffer, pDescr, len);  /* 加载上传数据 */
                        SetupLen -= len;
                        pDescr += len;
                        break;
                    case USB_SET_ADDRESS:
                        SetupLen = UsbSetupBuf->wValueL;  // 暂存USB设备地址
                        break;
                    case USB_GET_CONFIGURATION:
                        Ep0Buffer[0] = UsbConfig;
                        if ( SetupLen >= 1 ) len = 1;
                        break;
                    case USB_SET_CONFIGURATION:
                        UsbConfig = UsbSetupBuf->wValueL;
                        if(UsbConfig)
                        {
                            Ready = 1;                                                   //set config命令一般代表usb枚举完成的标志
                        }
                        break;
                    case USB_CLEAR_FEATURE:
                        if ((UsbSetupBuf->bRequestType & USB_REQ_RECIP_MASK ) == USB_REQ_RECIP_ENDP)  // 端点
                        {
                            switch(UsbSetupBuf->wIndexL)
                            {
                            case 0x82:
                                UEP2_CTRL = UEP2_CTRL & ~ ( bUEP_T_TOG | MASK_UEP_T_RES ) | UEP_T_RES_NAK;
                                break;
                            case 0x02:
                                UEP2_CTRL = UEP2_CTRL & ~ ( bUEP_R_TOG | MASK_UEP_R_RES ) | UEP_R_RES_ACK;
                                break;
                            case 0x81:
                                UEP1_CTRL = UEP1_CTRL & ~ ( bUEP_T_TOG | MASK_UEP_T_RES ) | UEP_T_RES_NAK;
                                break;
                            case 0x01:
                                UEP1_CTRL = UEP1_CTRL & ~ ( bUEP_R_TOG | MASK_UEP_R_RES ) | UEP_R_RES_ACK;
                                break;
                            default:
                                len = 0xFF;  // 不支持的端点
                                break;
                            }
                        }
                        else if((UsbSetupBuf->bRequestType & USB_REQ_RECIP_MASK ) == USB_REQ_RECIP_DEVICE)// 设备
                        {
                            WakeUpEnFlag = 0;
                            break;
                        }
                        else
                        {
                            len = 0xFFFF;                                                // 不是端点不支持
                        }
                        break;
                    case USB_SET_FEATURE:                                               /* Set Feature */
                        if((UsbSetupBuf->bRequestType & 0x1F) == 0x00)                    /* 设置设备 */
                        {
                            if(((( UINT16 )UsbSetupBuf->wValueH << 8 ) | UsbSetupBuf->wValueL) == 0x01)
                            {
                                if(CfgDesc[ 7 ] & 0x20)
                                {
                                    WakeUpEnFlag = 1;                                   /* 设置唤醒使能标志 */
                                }
                                else
                                {
                                    len = 0xFFFF;                                        /* 操作失败 */
                                }
                            }
                            else
                            {
                                len = 0xFFFF;                                            /* 操作失败 */
                            }
                        }
                        else if((UsbSetupBuf->bRequestType & 0x1F) == 0x02)        /* 设置端点 */
                        {
                            if((((UINT16)UsbSetupBuf->wValueH << 8 ) | UsbSetupBuf->wValueL) == 0x00)
                            {
                                switch(((UINT16)UsbSetupBuf->wIndexH << 8) | UsbSetupBuf->wIndexL)
                                {
                                case 0x82:
                                    UEP2_CTRL = UEP2_CTRL & (~bUEP_T_TOG) | UEP_T_RES_STALL;/* 设置端点2 IN STALL */
                                    break;
                                case 0x02:
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
void main(void)
{
    CfgFsys( );                                                           //CH557时钟选择配置
    mDelaymS(20);                                                         //修改主频等待内部晶振稳定,必加
    GPIO_Init(PORT0, PIN0 | PIN1 | PIN2 | PIN3 | PIN4 | PIN5 | PIN6 | PIN7, MODE0);
    GPIO_Init(PORT1, PIN0 | PIN1 | PIN2, MODE0);
    GPIO_Init(PORT3, PIN2, MODE0);
    GPIO_Init(PORT3, PIN3, MODE0);
    GPIO_Init(PORT3, PIN4, MODE0);
    GPIO_Init(PORT3, PIN5, MODE0);
    GPIO_INT_Init((INT_INT0_L | INT_INT1_L), INT_EDGE, Enable);           //外部中断配置INT0\INT1
    InitUSB_Device();                                                     //USB设备模式初始化
    IP_EX = bIP_USB;                                                      //调整USB中断优先级
    memset(HIDKey, 0, sizeof(HIDKey));                                    //清空缓冲区
    memset(HIDMouse, 0, sizeof(HIDMouse));

    while(1)
    {
        if(Ready)
        {
            HIDValueHandle();
        }
    }
}

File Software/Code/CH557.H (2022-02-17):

/*--------------------------------------------------------------------------
CH557.H
Header file for CH557 microcontrollers.
****************************************
**  Copyright  (C)  W.ch  1999-2018   **
**  Web:              http://wch.cn   **
****************************************
--------------------------------------------------------------------------*/

// 3 blocks: __BASE_TYPE__, __CH557_H__, __USB_DEF__
// define NO_XSFR_DEFINE before include CH557.H to disable xSFR define xdata address by _at_

#ifndef __BASE_TYPE__
#define __BASE_TYPE__

#ifdef __cplusplus
extern "C" {
#endif

/*----- constant and type define -----------------------------------------*/

#ifndef TRUE
#define TRUE    1
#define FALSE   0
#endif
#ifndef NULL
#define NULL    0
#endif

#ifndef BOOL
typedef bit                             BOOL;
#endif
#ifndef UINT8
typedef unsigned char                   UINT8;
#endif
#ifndef UINT16
typedef unsigned short                  UINT16;
#endif
#ifndef UINT32
typedef unsigned long                   UINT32;
#endif
#ifndef UINT8D
typedef unsigned char  data             UINT8D;
#endif
#ifndef UINT16D
typedef unsigned short data             UINT16D;
#endif
#ifndef UINT32D
typedef unsigned long  data             UINT32D;
#endif
#ifndef UINT8I
typedef unsigned char  idata            UINT8I;
#endif
#ifndef UINT16I
typedef unsigned short idata            UINT16I;
#endif
#ifndef UINT32I
typedef unsigned long  idata            UINT32I;
#endif
#ifndef UINT8X
typedef unsigned char  xdata            UINT8X;
#endif
#ifndef UINT16X
typedef unsigned short xdata            UINT16X;
#endif
#ifndef UINT32X
typedef unsigned long  xdata            UINT32X;
#endif
#ifndef UINT8V
typedef unsigned char volatile          UINT8V;
#endif
#ifndef UINT8DV
typedef unsigned char volatile data     UINT8DV;
#endif
#ifndef UINT8XV
typedef unsigned char volatile xdata    UINT8XV;
#endif
#ifndef UINT8PV
typedef unsigned char volatile pdata    UINT8PV;
#endif
#ifndef UINT8C
typedef const unsigned char code        UINT8C;
#endif
#ifndef PUINT8
typedef unsigned char                 *PUINT8;
#endif
#ifndef PUINT16
typedef unsigned short                *PUINT16;
#endif
#ifndef PUINT32
typedef unsigned long                 *PUINT32;
#endif
#ifndef PUINT8I
typedef unsigned char  idata          *PUINT8I;
#endif
#ifndef PUINT16I
typedef unsigned short idata          *PUINT16I;
#endif
#ifndef PUINT32I
typedef unsigned long  idata          *PUINT32I;
#endif
#ifndef PUINT8X
typedef unsigned char  xdata          *PUINT8X;
#endif
#ifndef PUINT16X
typedef unsigned short xdata          *PUINT16X;
#endif
#ifndef PUINT32X
typedef unsigned long  xdata          *PUINT32X;
#endif
#ifndef PUINT8V
typedef unsigned char volatile        *PUINT8V;
#endif
#ifndef PUINT8DV
typedef unsigned char volatile data   *PUINT8DV;
#endif
#ifndef PUINT8XV
typedef unsigned char volatile xdata  *PUINT8XV;
#endif
#ifndef PUINT8PV
typedef unsigned char volatile pdata  *PUINT8PV;
#endif
#ifndef PUINT8C
typedef const unsigned char code      *PUINT8C;
#endif

#ifndef STRUCT_OFFSET
#define STRUCT_OFFSET( s, m )       ( (UINT8)( & (((s) *)0) -> (m) ) )  /* get the offset address for a member of a structure */
#endif

#ifndef NO_XSFR_DEFINE
#define EXTERN
#define _AT_    _at_
#else
#define EXTERN  extern
#define _AT_    ;/##/
#endif

#ifdef __cplusplus
}
#endif

#endif  // __BASE_TYPE__

#ifndef __CH557_H__
#define __CH557_H__

#ifdef __cplusplus
extern "C" {
#endif

/*----- SFR --------------------------------------------------------------*/
/*  sbit are bit addressable, others are byte addressable */

/*  System Registers  */
sfr PSW             = 0xD0;         // program status word
 sbit CY            = PSW^7;        // carry flag
 sbit AC            = PSW^6;        // auxiliary carry flag
 sbit F0            = PSW^5;        // bit addressable general purpose flag 0
 sbit RS1           = PSW^4;        // register R0-R7 bank selection high bit
 sbit RS0           = PSW^3;        // register R0-R7 bank selection low bit
#define MASK_PSW_RS       0x18      // bit mask of register R0-R7 bank selection
// RS1 & RS0: register R0-R7 bank selection
//    00 - bank 0, R0-R7 @ address 0x00-0x07
//    01 - bank 1, R0-R7 @ address 0x08-0x0F
//    10 - bank 2, R0-R7 @ address 0x10-0x17
//    11 - bank 3, R0-R7 @ address 0x18-0x1F
 sbit OV            = PSW^2;        // overflow flag
 sbit F1            = PSW^1;        // bit addressable general purpose flag 1
 sbit P             = PSW^0;        // ReadOnly: parity flag
sfr ACC             = 0xE0;         // accumulator
sfr B               = 0xF0;         // general purpose register B
sfr A_INV           = 0xFD;         // ReadOnly: bit inversion of ACC (bit0<->bit7,bit1<->bit6,bit2<->bit5,bit3<->bit4, [7..0]->[0..7])
sfr SP              = 0x81;         // stack pointer
//sfr16 DPTR          = 0x82;         // DPTR pointer, little-endian
sfr DPL             = 0x82;         // data pointer low
sfr DPH             = 0x83;         // data pointer high
sfr SAFE_MOD        = 0xA1;         // WriteOnly: writing safe mode
//sfr CHIP_ID         = 0xA1;         // ReadOnly: reading chip ID
#define CHIP_ID           SAFE_MOD
sfr GLOBAL_CFG      = 0xB1;         // global config, Write@SafeMode
#define bBOOT_LOAD        0x20      // ReadOnly: boot loader status for discriminating BootLoader or Application: set 1 by power on reset, clear 0 by software reset
#define bSW_RESET         0x10      // software reset bit, auto clear by hardware
#define bCODE_WE          0x08      // enable flash-ROM (include code & Data-Flash) being program or erasing: 0=writing protect, 1=enable program and erase
#define bDATA_WE          0x04      // enable Data-Flash (flash-ROM data area) being program or erasing: 0=writing protect, 1=enable program and erase
#define bXIR_XSFR         0x02      // force MOVX_@R0/@R1 only for xSFR area: 0=MOVX_@R0/@R1 for standard xdata area include xRAM&xSFR, 1=MOVX_@R0/@R1 for xSFR only
#define bWDOG_EN          0x01      // enable watch-dog reset if watch-dog timer overflow: 0=as timer only, 1=enable reset if timer overflow
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

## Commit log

2022-02-17 upload CADFiles
    [FramWork(CAD2013).dwg, FramWork(CAD2022).dwg]
2022-02-17 upload Hardware files
    [SDVX.SchDoc]
2022-02-17 upload Software files
    [CompositeKM.obj, Debug.obj]
2022-02-18 update CADFriles
    [FramWork(CAD2013).dwg, FramWork(CAD2022).dwg]
2022-02-26 update CADFiles
    [FramWork(CAD2013).dwg, FramWork(CAD2022).dwg]
2022-02-27 update Software
    [CompositeKM.obj, Debug.obj, HID.obj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]
